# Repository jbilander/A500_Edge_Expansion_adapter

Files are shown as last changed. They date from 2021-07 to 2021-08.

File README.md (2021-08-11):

# A500_Edge_Expansion_adapter
A500 86pin edge connector adapter. Turns the expansion edge into a 86pin female socket inside the A500 case.

***

Caveat

In order to install the adaptor you will need to remove the motherboard from the A500 case temporarily, install and put mobo back with the adaptor on. There is not enough room/clearance to install through the sidecar port opening of the A500 case.

***

<a href="images/A500_86pin_internal_adapter_pic1.png">
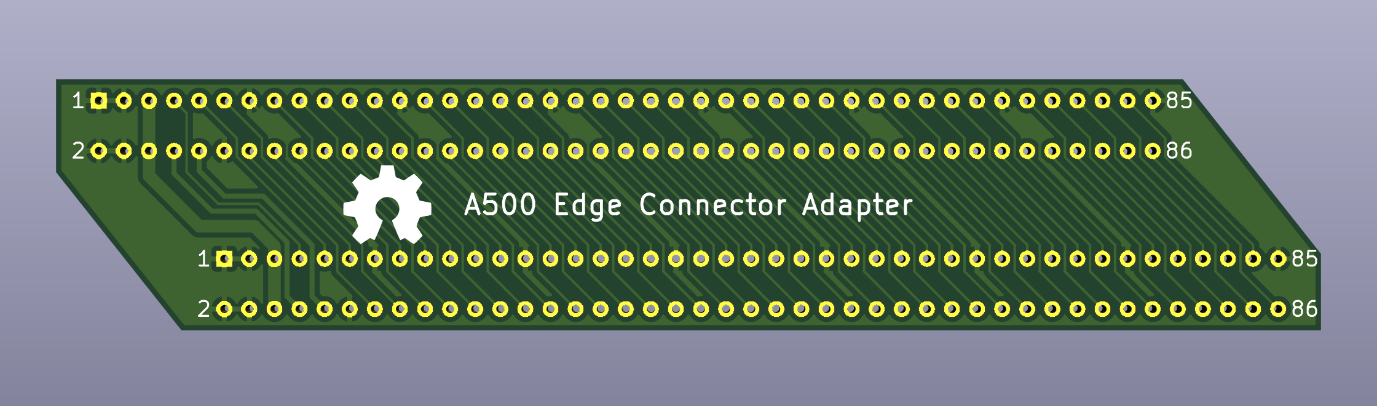
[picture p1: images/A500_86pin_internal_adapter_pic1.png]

</a>
<br />
<a href="images/A500_86pin_internal_adapter_pic2.png">
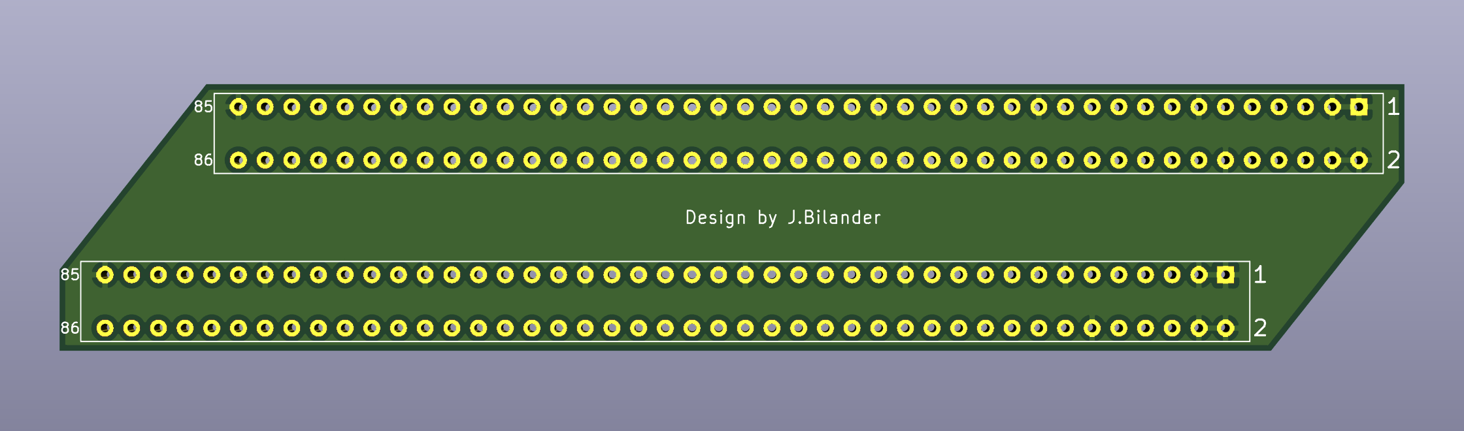
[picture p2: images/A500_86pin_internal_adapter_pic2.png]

</a>

***

86-pin connectors I sourced from here:<br />
https://www.aliexpress.com/item/33029711948.html

***

<a href="images/A500_86pin_internal_adapter_pic3.jpg">
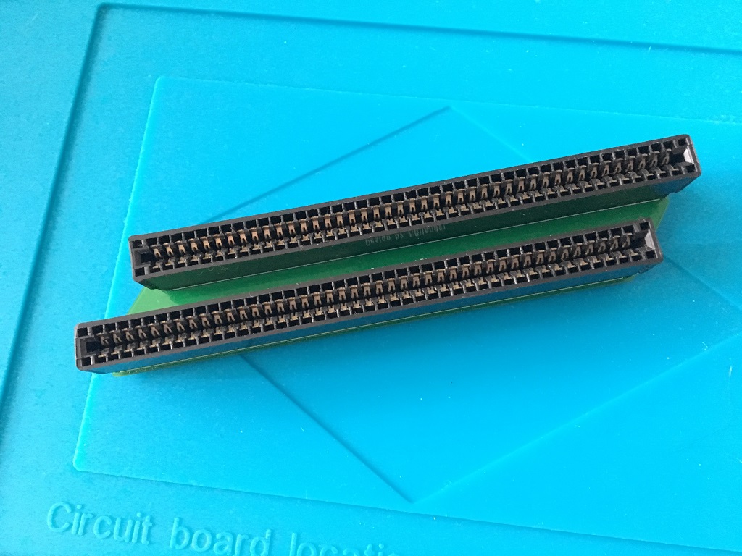
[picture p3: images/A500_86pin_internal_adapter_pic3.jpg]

</a>
<a href="images/A500_86pin_internal_adapter_pic4.jpg">
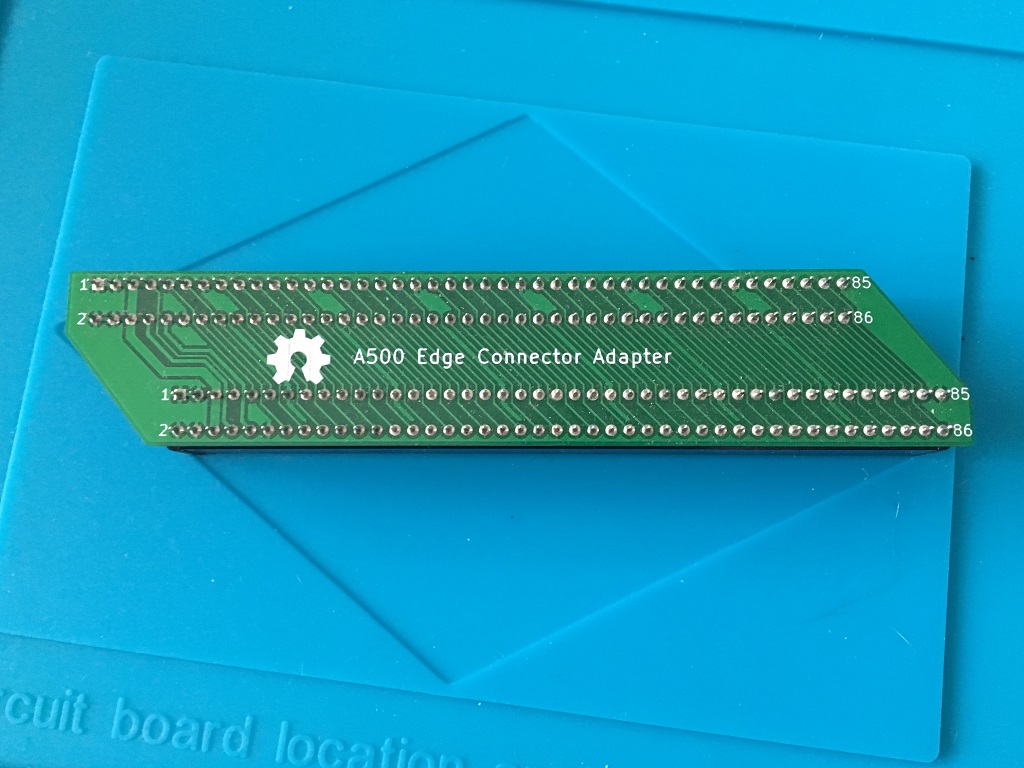
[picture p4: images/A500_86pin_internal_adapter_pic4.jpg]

</a>

***

While installing you might want to put a solder blob or put a 0 Ohm resistor on JP6 (Rev.6A mobo's) to connect through the 7 MHz clock. On Rev. 8A (A500+) it is already connected with a track on the PCB. I put a 0 Ohm resistor in picture below, and then put back the protective metal plate.

***

<a href="images/A500_86pin_internal_adapter_pic5.jpg">
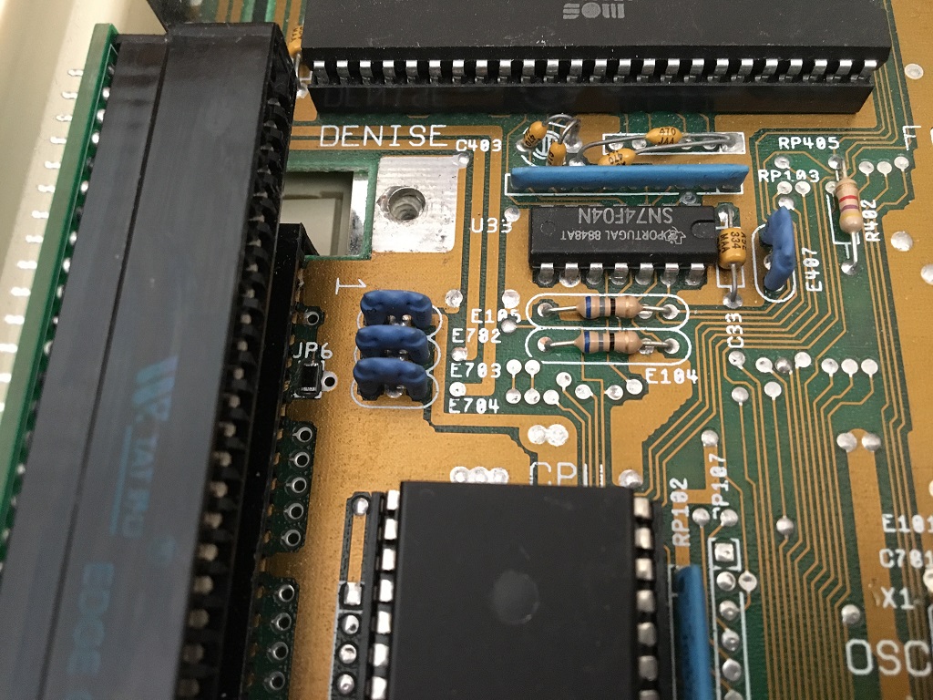
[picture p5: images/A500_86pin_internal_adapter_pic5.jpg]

</a>
<a href="images/A500_86pin_internal_adapter_pic6.jpg">
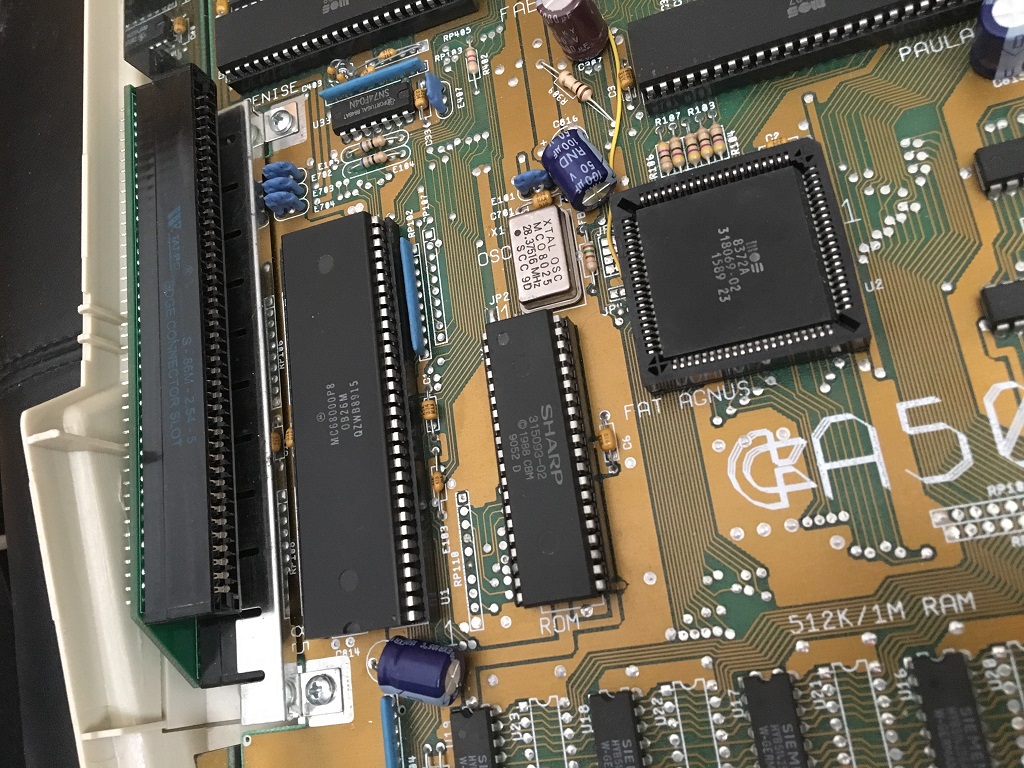
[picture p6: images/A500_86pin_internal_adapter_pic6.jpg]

</a>

***

The adapter clears the keyboard nicely, but not if the inserted card is too bulky towards the keyboard underside. The CPU fitted in the OpenAmiga2000CoproAdapter on picture below touches the keyboard underside, but this was only for temporary testing the edge adapter anyway.

***

<a href="images/A500_86pin_internal_adapter_pic7.jpg">
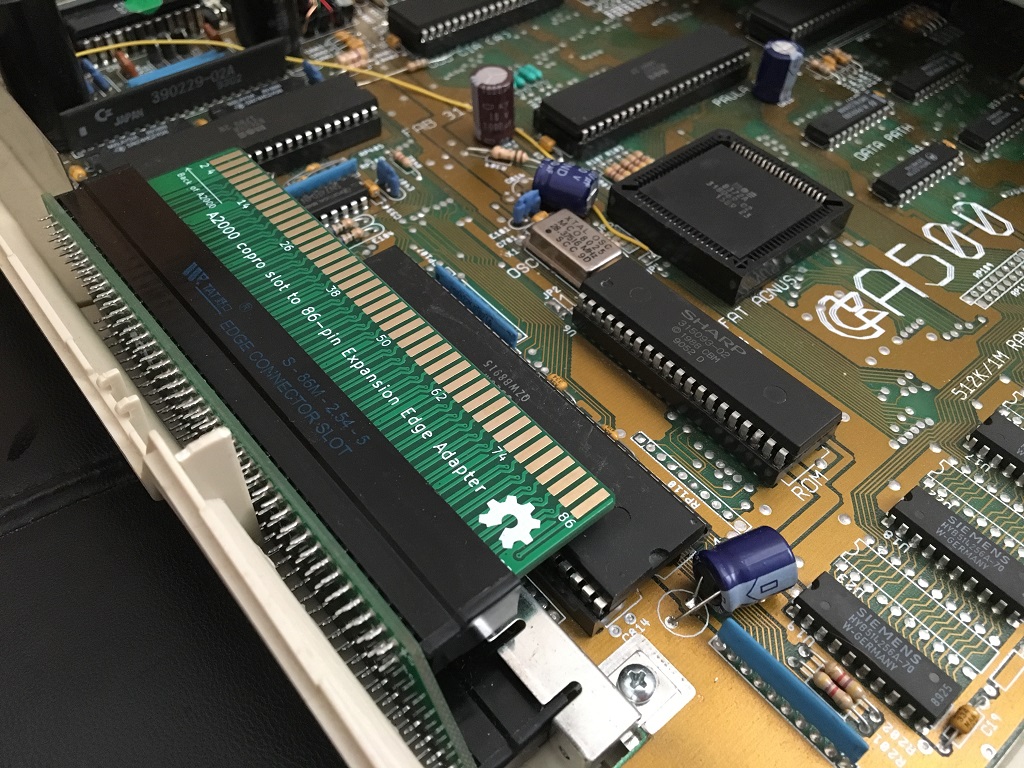
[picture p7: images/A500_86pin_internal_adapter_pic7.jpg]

</a>
<a href="images/A500_86pin_internal_adapter_pic8.jpg">
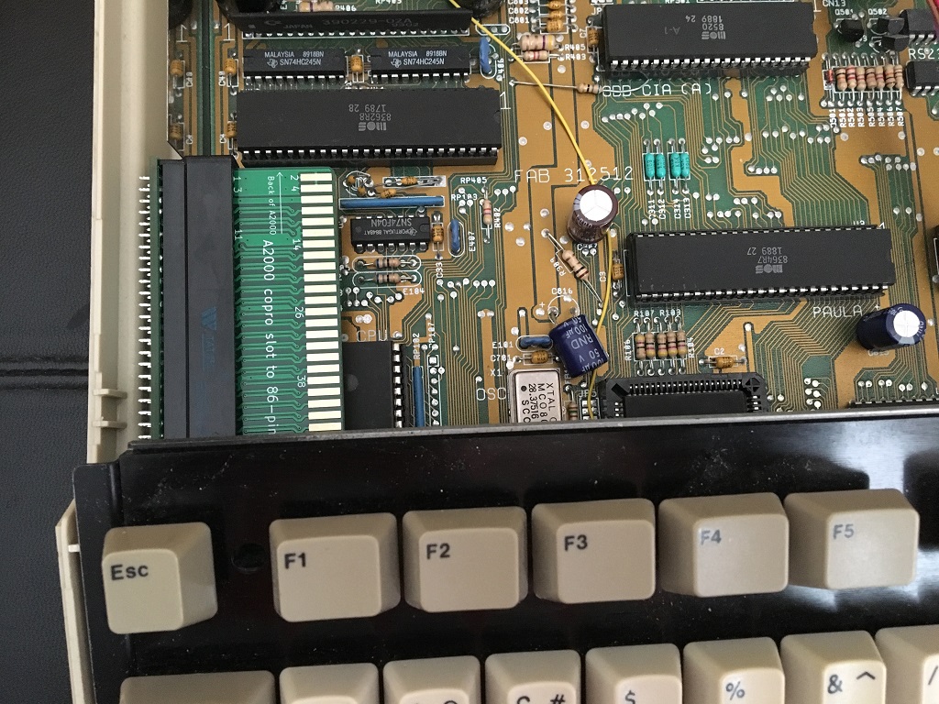
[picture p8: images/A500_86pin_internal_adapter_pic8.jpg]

</a>
<a href="images/A500_86pin_internal_adapter_pic9.jpg">
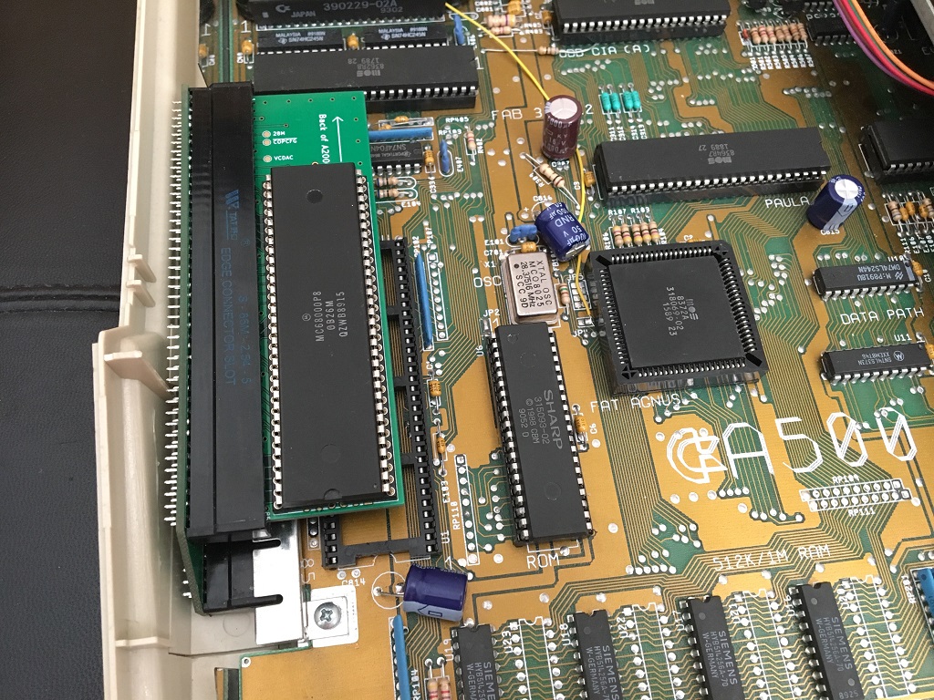
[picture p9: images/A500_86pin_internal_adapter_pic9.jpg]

</a>

***

[][cc-by-sa]

This work is licensed under a
[Creative Commons Attribution-ShareAlike 4.0 International License][cc-by-sa].

[][cc-by-sa]

[cc-by-sa]: http://creativecommons.org/licenses/by-sa/4.0/
[cc-by-sa-image]: https://licensebuttons.net/l/by-sa/4.0/88x31.png
[cc-by-sa-shield]: https://img.shields.io/badge/License-CC%20BY--SA%204.0-lightgrey.svg

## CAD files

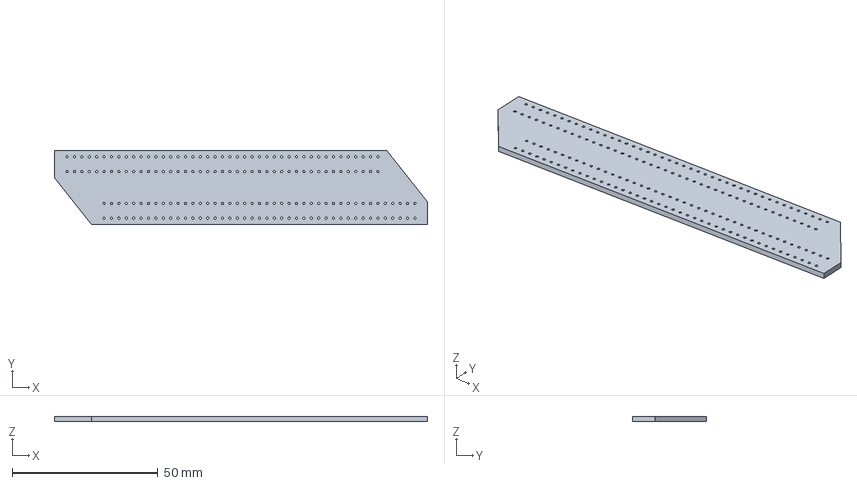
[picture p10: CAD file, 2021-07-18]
A500_86pin_internal_adapter.step
128.0 x 25.4 x 1.60 mm

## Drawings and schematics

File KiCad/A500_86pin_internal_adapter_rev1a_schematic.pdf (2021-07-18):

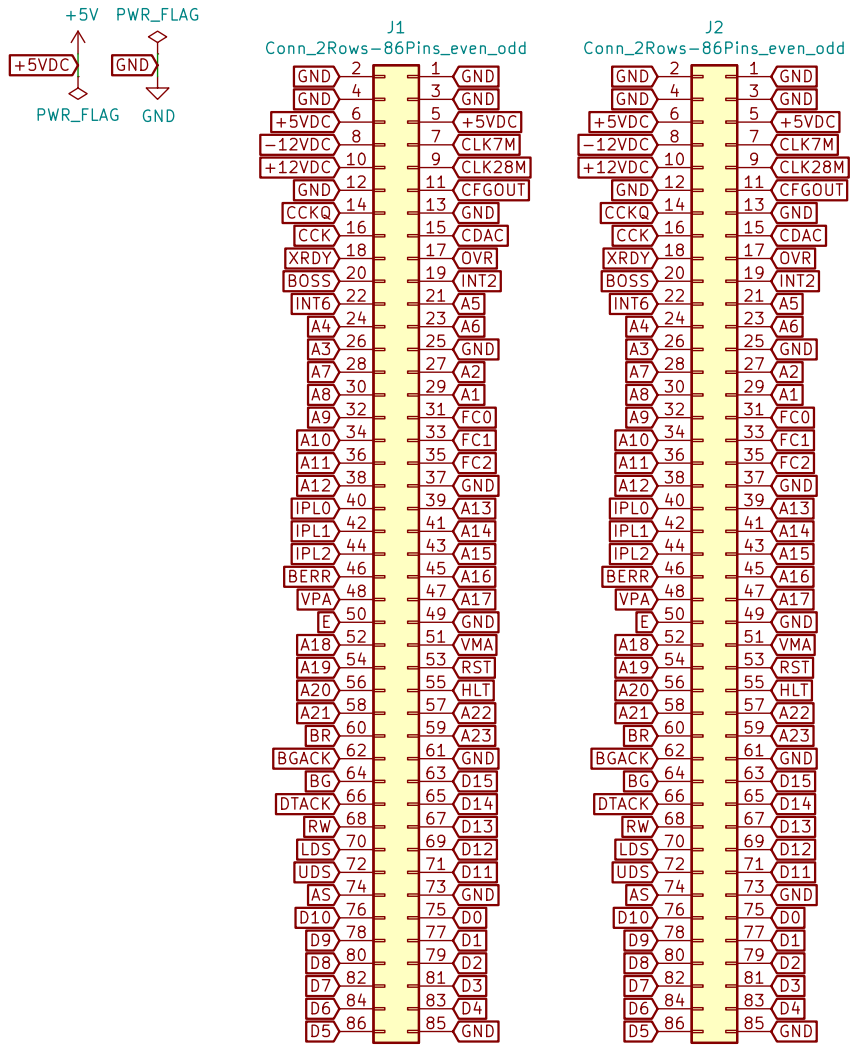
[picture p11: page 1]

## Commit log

2021-07-18 added KiCad files
    [A500_86pin_internal_adapter.kicad_pcb, A500_86pin_internal_adapter.sch]
2021-07-18 added Rev1A gerbers
2021-07-18 changed plot output folder to ./out
    [A500_86pin_internal_adapter.kicad_pcb]
2021-07-18 added schematic pdf
2021-07-18 added STEP-file
    [A500_86pin_internal_adapter.step]

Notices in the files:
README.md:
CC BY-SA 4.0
